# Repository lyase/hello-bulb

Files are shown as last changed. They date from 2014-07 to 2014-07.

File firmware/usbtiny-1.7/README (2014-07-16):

USBtiny
=======

USBtiny is a software implementation of the USB low-speed protocol for
the Atmel ATtiny microcontrollers. Of course, it will also work on the
ATmega series. The software is written for an AVR clocked at 12 MHz.
At this frequency, each bit on the USB bus takes 8 clock cycles, and
with a lot of trickery, it is possible to decode and encode the USB
waveforms by software. The USB driver needs approximately 1250 to 1350
bytes of flash space (excluding the optional identification strings),
depending on the configuration and compiler version, and 46 bytes RAM
(excluding stack space). The C interface consists of 3 to 5 functions,
depending on the configuration.

Implementation
==============

USB uses two differential data signals, D+ and D-, which are normally
complementary. However, the end of a packet is signalled by pulling
both signals low. Data is not transmitted directly on the USB bus, it
is NRZI encoded first. This means that a "0" bit is encoded as a bit
change, and a "1" bit is encoded as no bit change. After 6 "1" bits,
"bit stuffing" takes place to force a change on the USB signal lines.

The software is interrupt driven: the start of a USB packet triggers
an interrupt. The interrupt handler synchronizes with the sync byte,
removes the NRZI encoding and bit stuffing, and stores the packed in
one of the two RAM buffers. Two buffers are used so that the next
packet can be received while the current one is being processed.
Depending on the packet type, a reply packed may be sent back
immediately in the interrupt handler.

The rest of the USB driver is written in C. A usb_poll() function
must to be called periodically to poll for incoming packets. Only a
single endpoint is supported at the moment. Standard control requests
are directly handled by the USB driver. Other SETUP requests are
forwarded to a user-supplied function usb_setup(). Support for large
replies and OUT control requests is optional, see usbtiny.h.

To use the USB driver in your own application, you need to configure
the macros in usbtiny.h, and provide a function usb_setup() to handle
SETUP control packets. Optionally, you need to provide the functions
usb_in() and usb_out(). Your code needs to call the initialization
function usb_init() at program startup, and usb_poll() at regular
intervals. The AVR device type and the upload command should be
configured at the top of the Makefile.

Other USB projects
==================

This software was inspired by two similar USB projects for the AVR,
especially the second one:

  http://www.cesko.host.sk/IgorPlugUSB/IgorPlug-USB%20(AVR)_eng.htm
  http://www.obdev.at/products/avrusb/index.html

The IgorPlugUSB code and earlier versions of the obdev code had the
restriction that the D+ signal must be connected to bit 0 of an I/O
port, in addition to an interrupt input. That means that for devices
like the ATtiny2313, three I/O pins are required to control the USB bus.
One of the reasons I wrote USBtiny was to have more freedom over which
I/O pins to use for the D+ and D- USB signals. The only restriction
is that both signals should be on the same I/O port. When you select a
pin for D+ that can also generate an interrupt, only two I/O pins are
required. Later versions of the obdev code have also removed this
restriction. The pin-change interrupt is deliberately not used, so
that it remains available for other uses. Another improvement is an
optional faster CRC calculation that uses a lookup table to calculate
4 bits at a time.

Apart from these advantages, I think that my code is more readable and
easier to configure, but that impression may be caused by a mild form
of the NIH syndrome that I'm suffering from. In any case, I learned a
lot about the USB protocol, and writing the interrupt handler was a
nice puzzle.

The USBtinyISP project is an AVR in-circuit programmer based on USBtiny,
and is available as a kit:

  http://www.ladyada.net/make/usbtinyisp/

Hardware
========

The AVR must be clocked with an external 12 MHz crystal. For an
ATtiny2313, this means that the low fuse byte must be reprogrammed,
for instance to 0xef. I also recommend to enable the BOD circuit,
when available. For the ATtiny2313, this means programming the high
fuse byte to 0xdb (BOD level is 2.7V).

The USB data signals are specified at 3.3V. The easiest way to
accomplish this is to use a 3.3V power supply for the AVR. However,
driving the USB signals with 5V seems to work as well in most cases,
which may be more convenient when you need to interface to 5V
peripherals. According to the USB specification, a device should not
be damaged by 5V signals. I've been running the AVR and USB bus at 5V,
and haven't encounter any problems so far, but I have some reports
of PCs and laptops that do not work with 5V signals. In that case,
you can reduce the voltage of the USB data signals by adding 3V6 zener
diodes from the data signals to ground.

USBtiny SPI converter
=====================

My first USBtiny application is a USB to SPI (Serial Programming
Interface) converter. The SPI signals are connected to a female DB-25
connecter, so that the converter can be plugged onto my AVR parallel
port programmer. Because the most important parallel port signals are
connected to the DB-25 connecter, the same hardware (with different
firmware) could be used to control other parallel port devices. That
is also the reason why I connected the ACK signal to the INT1 pin.
The software, the schematic and a Python test script can be found
in the "spi" subdirectory.

My AVR parallel port programmer follows the "bsd" design from Brian
Dean (http://www.bsdhome.com/avrdude/). For safety, I've used series
resistors in the output signals. The Atmel device is powered by the
data lines D1-D3, via 220 Ohm resistors. D0 is used to control a LED.
Here is an ASCII-art version of the schematic:

DB25 male                          ATtiny2313
---------                          ----------
18 GND ----------------------+---- 10 GND
 2 D0  ---- 330 ---- LED ----+
 3 D1  ---- 220 ---+
 4 D2  ---- 220 ---+-------------- 20 VCC
 5 D3  ---- 220 ---+
 7 D5  ---- 1K -------------------  1 /RESET
 8 D6  ---- 680 ------------------ 19 SCK
 9 D7  ---- 1K ------------------- 17 MOSI
10 ACK --------------------------- 18 MISO

The USBtiny circuit may be powered via the diode at pin 14 of the
DB-25 connector to enable reprograming the ATtiny2313 in-system.
This requires an adaptor cable between another SPI programmer and
a DB-25 male connector with the following connections:

  SPI  DB25
  ---  ----
  GND    25
  VCC    14
  RESET  13
  SCK     9
  MISO    8
  MOSI    7

Bit-banging the SPI signals via USB turned out to be very slow. To get
reasonable programming speeds, I've moved the SPI algorithm into the
AVR. This means that you can send a 32-bit SPI command in a single USB
packet. In addition, you can read or write up to 255 bytes from/to
flash or EEPROM in a single control transfer.

The subdirectory "patches" contains a patch for avrdude-5.4 that adds
support for controlling this SPI converter. The programmer name is
"usbtiny". You can use the -B option or the "sck" command to specify
the minimum SCK period in microseconds (range: 1..250, default: 10).
Native support for USBtiny was added in avrdude version 5.5.

USBtiny LIRC compatible IR receiver and LCD controller
======================================================

A second USBtiny application is a receiver for infrared remote
controls that can be used with the LIRC package (http://www.lirc.org/).
The firmware stores the mark/space timings from a TSOP1738 IR decoder
in a buffer that is polled by a LIRC device driver. As a visual
feedback, a LED is flashed when a signal is being received. As an
additional (optional) feature, a 2x16 LCD display is attached to PORTB.
You can control the display via the USB bus. The software, the schematic
and a Python test script can be found in the "ir" subdirectory.
A pull-down resistor at PB3 prevents a hang in the LCD initialization
code when no LCD is attached to PORTB. You can disable the LCD code by
setting the LCD_PRESENT macro in main.c to 0.

I adopted the "IgorPlug-USB" protocol, so that the existing LIRC
device driver "igorplugusb" could be used without modifications.
Nevertheless, patches for lirc-0.8.0 and lirc-0.8.2 are included
in the "patches" subdirectory, with the following modifications:
1) An increase of the sample rate from 10 to 100 times per second.
   This is not required, but improves the responsiveness and repeat
   behavior for some remote controls.
2) A fix from Reinhard Max to get correct gap timings.
3) A compilation fix for the latest 2.6 Linux kernels (lirc-0.8.0).

USB AVR programmer and SPI interface
====================================

The subdirectory "usbtinyisp" contains a modified version of the "spi"
application, that was adapted for use in the USBtinyISP AVR programmer
(http://www.ladyada.net/make/usbtinyisp/). The code works for both v1.0
and v2.0 devices.

Template USBtiny application
============================

The directory "template" contains a minimal template application that
can be used as a starting point for new USBtiny applications.

Tools
=====

The software was developed on a Linux system. In addition to standard
tools like GNU make, you need the AVR versions of gcc, binutils and
glibc to build the code: On a Debian/Ubuntu system, you can apt-get
the following packages:

  gcc-avr
  binutils-avr
  avr-libc

To upload the code to an AVR, I use avrdude with a parallel port
programmer.

I initially used gcc-3.4.3 with the -Os option, which generates
reasonable compact code. Unfortunately, newer versions like gcc-4.1.0
generated about 10% more code, and as a result, the application code
did not fit in 2K anymore. To make it fit, I had to remove the optional
vendor and device strings, by undefining the USBTINY_VENDOR_NAME and
USBTINY_DEVICE_NAME macros. Fortunately, code generation has improved
in later versions such as gcc-4.3.4.

The schematics were created with gschem, from the geda-gschem package.
The conversion to Postscript is done with a script that invokes gschem
non-interactively.

The "util" and application code subdirectories each contain their own
Makefile. In addition, there is a global Makefile that recursively
invokes all other Makefiles.

Host software
=============

The subdirectory "utils" contains a Python module "usbtiny.py" that
defines a class USBtiny that can be used to communicate with the
USBtiny firmware. This class is used by the test scripts.

The usbtiny.py module uses a Python wrapper around libusb that is
generated by "swig". Type "make" to build the wrapper. You need to
have swig, libusb, libusb-dev and python-dev installed on your system.

Libusb needs appropriate permissions to open a USB device. This means
that you either have to run the scripts as "root", or you should
configure the hotplug or udev system to relax the permissions of the
device file created under /proc/bus/usb/ when the device is plugged
in. For instance, you can create a file 99-usbtiny.rules with the
following content in /etc/udev/rules.d/:

  SUBSYSTEM=="usb",ATTR{idVendor}=="1781",ATTR{idProduct}=="0c9f",GROUP="plugdev"

License
=======

The USBtiny software is licensed under the terms of the GNU General
Public License as published by the Free Software Foundation, either
version 2 of the license, or (at your option) any later version. A
copy of the GPL version 2 license can be found in the file COPYING.

Author & website
================

Dick Streefland <dick@streefland.net>

http://www.google.com/search?btnI&q=webtag_net_streefland_avr_usbtiny

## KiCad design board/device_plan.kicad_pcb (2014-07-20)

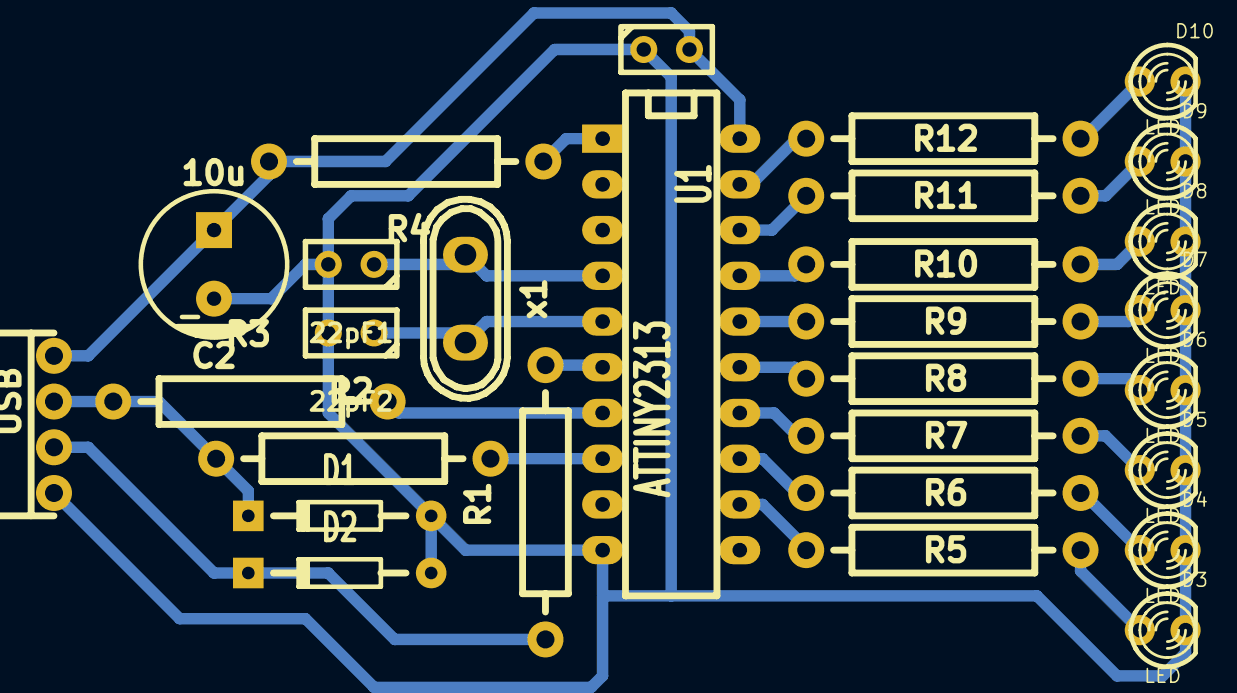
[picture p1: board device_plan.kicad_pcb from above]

Board: 2 copper layers, 29 parts (0 on the bottom side), 26 nets.

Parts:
22pF1, 22pF2: C; Capacitor3MMDiscRM2.5
C1: 100n; Capacitor3MMDiscRM2.5
C2: 10u; Capacitor8x13RM3.8
D1, D2: 3.6V; Diode_DO-35_SOD27_Horizontal_RM10
D3, D4, D5, D6, D7, D8, D9, D10: LED; LED-3MM
J1: USB; KK04_MC
R1, R2: 68 ohms; Resistor_Horizontal_RM15mm
R3: 1500 ohms; Resistor_Horizontal_RM15mm
R4: 10 kohms; Resistor_Horizontal_RM15mm
R5, R6, R7, R8, R9, R10, R11, R12: 47 ohms; Resistor_Horizontal_RM15mm
U1: ATTINY2313; DIP-20__300_ELL
x1: 12M; Crystal_HC50-U_Vertical

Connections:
GND: 22pF1.2, 22pF2.2, C1.1, C2.2, D1.1, D2.1, D3.2, D4.2, D5.2, D6.2, D7.2, D8.2, D9.2, D10.2, J1.4, U1.10
unnamed: 22pF1.1, U1.4, x1.1
unnamed: 22pF2.1, U1.5, x1.2
unnamed: D1.2, J1.2, R2.1, R3.1
unnamed: D2.2, J1.3, R1.1
unnamed: D3.1, R5.1
unnamed: D4.1, R6.1
unnamed: D5.1, R7.1
unnamed: D6.1, R8.1
unnamed: D7.1, R9.1
unnamed: D8.1, R10.1
unnamed: D9.1, R11.1
unnamed: D10.1, R12.1
unnamed: R1.2, U1.6
unnamed: R2.2, U1.8
unnamed: R3.2, U1.7
unnamed: R4.1, U1.1
unnamed: R5.2, U1.12
unnamed: R6.2, U1.13
unnamed: R7.2, U1.14
unnamed: R8.2, U1.15
unnamed: R9.2, U1.16
unnamed: R10.2, U1.17
unnamed: R11.2, U1.18
unnamed: R12.2, U1.19
VCC: C1.2, C2.1, J1.1, R4.2, U1.20

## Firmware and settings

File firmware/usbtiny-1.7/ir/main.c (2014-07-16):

// ======================================================================
// IR receiver and LCD controller with USB interface.
//
// Read IR mark/space patterns from a TSOP1738 on the ICP input pin.
// Mark and space periods are measured in units of 12Mhz/1024, which is
// 85.33 us. Up to 36 periods are stored in a buffer, where they can
// be read via a USB request. The buffer layout and USB requests are
// compatible with the "IgorPlug-USB" device, which is supported by LIRC
// through the "igorplugusb" driver. This implementation should also
// work with that driver. If IgorPlug-USB compatibility is not required,
// the resolution could be improved by reducing SCALING to 9, and you
// could also get rid of the additional endpoint (USBTINY_ENDPOINT).
//
// There are some IR protocols with very long packets length, such as
// the "NEC" protocol (http://www.sbprojects.com/knowledge/ir/nec.htm).
// This protocol uses 67 mark/space periods, which is too much for the
// limited amount of RAM in the ATtiny2313. Simply truncating the
// packet to the amount of available buffer space is not an option,
// because the significant bits are at the end of the packet. Instead,
// a buffer of 36 bytes (IR_MAX) is used, of which the last 16 bytes
// (IR_WRAP) are used as a circular buffer. Because both the address
// (16 periods) and the command code (16 periods) are sent twice (normal
// and inverted), the wrapping will result in a buffer with both the
// device address and the inverted command code. Other IR protocols are
// typically shorter than 36 periods.
//
// 16-bit Timer1 is initialized in normal mode with a clock of 12MHz/8.
// Both the positive and negative edges of the IR input signal on the
// ICP input pin trigger an input capture interrupt, because the edge
// selection is toggled on every interrupt. Output compare register A
// is used for a timeout to detect the end of an IR transmission.
// The timeout value is updated on every edge. When at least 4 edges
// were detected when a timeout occurs, the packet count ir.count is
// incremented and the ir.length byte is set to the packed length. This
// byte is checked when a read request is received via USB to see if a
// packet is available
//
// The two interrupt handlers in this file run for more than 28 cycles,
// so they need to reenable interrupts to allow USB interrupts to be
// handled in time. To avoid nested IR interrupts, the input capture and
// output compare interrupts are disabled before the global interrupt
// flag is set. In the input capture interrupt handler, the interrupts
// are disabled for a maximum of 27, 27 and 27 cycles, and in the output
// compare interrupt handler for 21, 23 and 22 cycles. Unfortunately,
// it was not possible to meet the 28 cycle maximum for the input
// capture interrupt handler without using some inline assembly.
// Because the limits are so tight, the code is fragile, and may break
// for a new gcc version.
//
// The IR receiver is disabled during an IR buffer read, so that a
// packet that is being tranmitted to the host, is not overwritten by
// the next packet. When a transfer is in progress, 'inpos' has a value
// other than 0xff. When the buffer is read completely, the IR receiver
// is reenabled again, but when the next IR packet has already started,
// this packed is discarded by setting 'edges' to 0xff.
//
// There are two USB request codes to control the LCD, one to write
// instructions, and one to write data to the display. OUT transfers
// are used to transfer up to 255 bytes for a single request.
//
// Stack space calculations for gcc-4.1.0 and gcc-4.3.4:
//
//   0  main (stack reset)
//   0      lcd_init (inlined)
//   0      ir_init (inlined)
//   2      usb_init
//   5      usb_poll
//   0          usb_receive (inlined)
//   2              usb_setup
//   5              usb_out
//   3                  lcd_write
//   0                      lcd_read4 (inlined)
//   2                      lcd_write4
//   0          usb_transmit (inlined)
//   4              usb_int
//   2              crc
//
// Maximum stack space is 5+5+3+2=15.
// Total stack usage:
// - USB interrupt:			11 bytes
// - IR input capture interrupt:	12 bytes
// - IR output compare interrupt: 	 7 bytes
// - main():				15 bytes
// The two IR interrupt handler cannot be active simultaneously, so the
// maximum stack space is 15+12+11=38 bytes.
//
// NOTE: The above cycle and stack size figures were obtained by
//       inspecting the code generated by gcc-4.1.0 and gcc-4.3.4.
//       Other compiler versions may generate different code, leading
//       to different figures.
//
// Copyright 2006-2010 Dick Streefland
//
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
#include <avr/io.h>
#include <avr/interrupt.h>
#include "def.h"
#include "usb.h"

// ----------------------------------------------------------------------
// IR receiver definitions
// ----------------------------------------------------------------------

#define	TIMEOUT		10500	// IR transmission timeout in us
#define	IR_MAX		36	// maximum number of IR data bytes
#define	IR_WRAP		16	// wrap area at end (for 67 byte NEC protocol)
#define	SCALING		10	// 9: 42.67 us period, 10: 85.33 us period
#define	LED		(D,5)	// I/O port for LED

enum
{
	// Generic requests
	USBTINY_ECHO,		// echo test
	// IgorPlug-USB requests
	IGORPLUG_CLEAR,		// clear IR data
	IGORPLUG_READ,		// read IR data (wValue: offset)
	// LCD requests
	LCD_INSTR = 20,		// write instructions to LCD (via OUT)
	LCD_DATA,		// write data to LCD (via OUT)
};

static	byte_t	inpos;		// read position for usb_in(), or 0xff
static	byte_t	edges;		// incremented for each edge
static	struct			// IgorPlug-USB compatible data layout
{
	byte_t	length;		// length of data[]
	byte_t	count;		// incremented for each IR packet
	byte_t	offset;		// not used
	byte_t	data[IR_MAX];	// mark/space periods
}		ir;

// ----------------------------------------------------------------------
// LCD definitions
// ----------------------------------------------------------------------

#define	LCD_PRESENT	1	// set to 0 to remove LCD support

#define	DDR		DDRB
#define	PORT		PORTB
#define	PIN		PINB

#define	D4		0
#define	RS		4
#define	RW		5
#define	E		6

#define	MASK_D4		(0xf << D4)
#define	MASK_RS		(1 << RS)
#define	MASK_RW		(1 << RW)
#define	MASK_E		(1 << E)

#ifndef	ICIE1
#define	ICIE1		TICIE1
#endif

// ----------------------------------------------------------------------
// Handler for timer1 input capture interrupt: edge on IR input
// ----------------------------------------------------------------------
ISR(TIMER1_CAPT_vect)
{
	static	uint_t	prev;
	uint_t		stamp;
	byte_t		delta;
	byte_t		e;

	TIMSK = 0;				// disable both IR interrupts
	sei();					// allow USB interrupt
	TCCR1B ^= _BV(ICES1);			// toggle edge detector
	stamp = ICR1;				// get time stamp
	asm volatile(
		"push	%A0\n"			// save stamp
		"push	%B0\n"
		:
		: "w"(stamp), "w"(prev)		// "w"(prev) reduces register usage
	);
	stamp -= prev;				// calculate delta in-place
	stamp += 1 << (SCALING - 3 - 1);	// round
	stamp >>= (SCALING - 3);		// scale
	asm volatile(
		"mov	%0,%A1\n"		// delta = stamp & 0xff
		"pop	%B1\n"
		"pop	%A1\n"			// restore stamp
		: "=r"(delta)
		: "w"(stamp)
	);
	prev  = stamp;
	OCR1A = stamp + 12L * TIMEOUT / 8;	// update timeout value
	cli();					// enter critical region
	e = edges;
	if	( e != 0xff )			// packet should not be ignored?
	{
		if	( e > IR_MAX )		// packet too long for buffer?
		{
			e -= IR_WRAP;		// wrap, don't truncate
		}
		if	( inpos == 0xff )	// update ir only when USB idle
		{
			ir.length = 0;		// discard previous packet
			if	( e > 0 )
			{
				ir.data[e - 1] = delta;
			}
		}
		edges = e + 1;
	}
	sei();					// allow USB interrupt
	SET(LED);				// switch LED on
	e = _BV(OCIE1A) | _BV(ICIE1);
	asm volatile("" :: "r"(e));		// force evaluation of "e"
	cli();
	TIMSK = e;				// reenable IR interrupts
}

// ----------------------------------------------------------------------
// Handler for timer1 output compare A interrupt: IR transmission timeout
// ----------------------------------------------------------------------
ISR(TIMER1_COMPA_vect)
{
	TIMSK = 0;				// disable both IR interrupts
	sei();					// allow USB interrupt
	CLR(LED);				// switch LED off
	cli();					// enter critical region
	if	(  edges >= 4			// at least two pulses (NEC)
		&& edges != 0xff		// packet should not be ignored
		&& inpos == 0xff		// update ir only when USB idle
		)
	{
		ir.count++;
		ir.length = edges - 1;		// new packet is complete
	}
	edges = 0;
	sei();					// allow USB interrupt
	TCCR1B &= ~_BV(ICES1);			// reset to negative edge
	cli();
	TIMSK = _BV(OCIE1A) | _BV(ICIE1);	// reenable IR interrupts
}

// ----------------------------------------------------------------------
// Initialize the IR receiver.
// ----------------------------------------------------------------------
static	void	ir_init ( void )
{
	OUTPUT(LED);
	TCCR1B = _BV(ICNC1)	// noise canceler, trigger on negative edge
	       | _BV(CS11);	// clock source clk/8
	TIMSK  = _BV(OCIE1A)	// output compare 1A match interrupt enable
	       | _BV(ICIE1);	// input capture 1 interrupt enable
}

#if	LCD_PRESENT
// ----------------------------------------------------------------------
// Delay <count> times 100 microseconds.
// ----------------------------------------------------------------------
__attribute__((noinline))
static	void	lcd_delay100u ( byte_t count )
{
	asm volatile(
		"0:	ldi	r25, 240\n"
		"1:	rjmp	2f\n"
		"2:	dec	r25\n"
		"	brne	1b\n"	// 240 * 5 cycles = 100us
		"	dec	r24\n"
		"	brne	0b\n"
	);
}

// ----------------------------------------------------------------------
// Write 4 bits to the LCD.
// ----------------------------------------------------------------------
__attribute__((noinline))
static	void	lcd_write4 ( byte_t data )
{
	PORT = (PORT & ~ MASK_D4) | (data << D4);
	PORT |= MASK_E;			// E high period: > 230ns
	DDR  = MASK_RS | MASK_RW | MASK_E | MASK_D4; // Dx setup time: > 80ns
	PORT &= ~ MASK_E;		// hold time: > 10ns
	DDR  = MASK_RS | MASK_RW | MASK_E;
}

// ----------------------------------------------------------------------
// Read 4 bits from the LCD.
// ----------------------------------------------------------------------
__attribute__((always_inline))
static	inline	byte_t	lcd_read4 ( void )
{
	byte_t	save;
	byte_t	data;

	save = PORT;
	PORT = MASK_RW;			// address setup time: > 40ns
	PORT |= MASK_E;			// E high period: > 230ns
	asm volatile("rjmp 0f\n0:");
	data = (PIN & MASK_D4) >> D4;	// data access time: > 160ns
	PORT = save;
	return data;
}

// ----------------------------------------------------------------------
// Write a byte to the LCD.
// ----------------------------------------------------------------------
static	void	lcd_write ( byte_t b )
{
	byte_t	h;

	do
	{
		h = lcd_read4();
		(void) lcd_read4();
	} while	( h & 0x08 );
	lcd_write4( b >> 4 );
	lcd_write4( b & 15 );
}

// ----------------------------------------------------------------------
// Initialize the LCD.
// ----------------------------------------------------------------------
static	void	lcd_init ( void )
{
	DDR = MASK_RS | MASK_RW | MASK_E;
	PORT = 0;
	//lcd_delay100u( 150 );	-- skipped because of RESET delay
	lcd_write4( 3 );
	lcd_delay100u( 41 );
	lcd_write4( 3 );
	lcd_delay100u( 1 );
	lcd_write( 0x32 );	// switch to 4-bit mode
	lcd_write( 0x28 );	// function set: 4-bit mode, two lines
	lcd_write( 0x01 );	// clear display
	lcd_write( 0x06 );	// entry mode: increment, no shift
	lcd_write( 0x0c );	// display control: on, no cursor
}
#endif	/* LCD_PRESENT */

// ----------------------------------------------------------------------
// Handle a non-standard SETUP packet.
// ----------------------------------------------------------------------
extern	byte_t	usb_setup ( byte_t data[8] )
{
	byte_t	req;
	byte_t	r;

	r = 0;

	// Generic requests
	req = data[1];
	if	( req == USBTINY_ECHO )
	{
		r = 8;
	}

	// IgorPlug-USB requests
	if	( req == IGORPLUG_CLEAR )
	{
		ir.length = 0;
		inpos = 0xff;
	}
	if	( req == IGORPLUG_READ )
	{
		cli();
		if	( ir.length > 0 )
		{
			inpos = data[2];
			r = 0xff;	// call usb_in() to get the data
		}
		else
		{
			data[0] = 0;
			r = 1;
		}
		sei();
	}

	// LCD requests
	if	( req == LCD_INSTR )
	{
		PORT &= ~ MASK_RS;	// data will be received by usb_out()
	}
	if	( req == LCD_DATA )
	{
		PORT |= MASK_RS;	// data will be received by usb_out()
	}

	return r;
}

// ----------------------------------------------------------------------
// Handle an IN packet.
// ----------------------------------------------------------------------
extern	byte_t	usb_in ( byte_t* data, byte_t len )
{
	byte_t	n;
	byte_t	max;

	max = ir.length + 3;
	n = 0;
	while	( n < len )
	{
		if	( inpos >= max )	// end of packet?
		{
			cli();
			if	( edges )	// next packet already started?
			{
				edges = 0xff;	// ignore remainder of packet
			}
			inpos = 0xff;		// reenable receiver
			sei();
			break;
		}
		data[n++] = (& ir.length)[inpos++];
	}
	return n;
}

// ----------------------------------------------------------------------
// Handle an OUT packet.
// ----------------------------------------------------------------------
extern	void	usb_out ( byte_t* data, byte_t len )
{
#if	LCD_PRESENT
	while	( len )
	{
		lcd_write( *data++ );
		len--;
	}
#endif	/* LCD_PRESENT */
}

// ----------------------------------------------------------------------
// Main
// ----------------------------------------------------------------------
extern	int	main ( void )
{
	SPL = (RAMEND & 0xff);			// drop return address of main
	inpos = 0xff;
#if	LCD_PRESENT
	lcd_init();
#endif	/* LCD_PRESENT */
	ir_init();
	usb_init();
	for	( ;; )
	{
		usb_poll();
	}
}

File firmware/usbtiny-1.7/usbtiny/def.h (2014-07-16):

// ======================================================================
// Common definitions for the USB driver
//
// Copyright 2006-2010 Dick Streefland
//
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
#ifdef __ASSEMBLER__
#define	__SFR_OFFSET		0
#endif
#include <avr/io.h>
#include "usbtiny.h"

// Preprocessor magic
#define	CAT2(a,b)		CAT2EXP(a, b)
#define	CAT2EXP(a,b)		a ## b
#define	CAT3(a,b,c)		CAT3EXP(a, b, c)
#define	CAT3EXP(a,b,c)		a ## b ## c

// I/O Ports for USB
#define	USB_IN			CAT2(PIN, USBTINY_PORT)
#define	USB_OUT			CAT2(PORT, USBTINY_PORT)
#define	USB_DDR			CAT2(DDR, USBTINY_PORT)

// I/O bit masks for USB
#define	USB_MASK_DMINUS		(1 << (USBTINY_DMINUS))
#define	USB_MASK_DPLUS		(1 << (USBTINY_DPLUS))
#define	USB_MASK		(USB_MASK_DMINUS | USB_MASK_DPLUS)

// Interrupt configuration
#if	defined	EICRA
#  define USB_INT_CONFIG	EICRA
#else
#  define USB_INT_CONFIG	MCUCR
#endif
#define	USB_INT_CONFIG_SET	((1 << CAT3(ISC,USBTINY_INT,1)) | (1 << CAT3(ISC,USBTINY_INT,0)))
#define USB_INT_VECTOR		CAT3(INT, USBTINY_INT, _vect)

// Interrupt enable
#if	defined	GIMSK
#  define USB_INT_ENABLE	GIMSK
#elif	defined	EIMSK
#  define USB_INT_ENABLE	EIMSK
#else
#  define USB_INT_ENABLE	GICR
#endif
#define	USB_INT_ENABLE_BIT	CAT2(INT,USBTINY_INT)

// Interrupt pending bit
#if	defined	EIFR
#  define USB_INT_PENDING	EIFR
#else
#  define USB_INT_PENDING	GIFR
#endif
#define	USB_INT_PENDING_BIT	CAT2(INTF,USBTINY_INT)
#if	defined INF0 && ! defined INTF0
#  define	INTF0		INF0	// fix for incorrect definition in iotn13.h
#endif

// USB PID values
#define	USB_PID_SETUP		0x2d
#define	USB_PID_OUT		0xe1
#define	USB_PID_IN		0x69
#define	USB_PID_DATA0		0xc3
#define	USB_PID_DATA1		0x4b
#define	USB_PID_ACK		0xd2
#define	USB_PID_NAK		0x5a
#define	USB_PID_STALL		0x1e

// Various constants
#define	USB_BUFSIZE		11	// PID + data + CRC

// Bit manipulation macros
#define	BIT_CLR(reg,bit)	{ (reg) &= ~ _BV(bit); }
#define	BIT_SET(reg,bit)	{ (reg) |=   _BV(bit); }
#define	BIT_TST(reg,bit)	(((reg) & _BV(bit)) != 0)

// I/O port manipulation macros
#define	DDR_CLR(p,b)		BIT_CLR(DDR  ## p, b)
#define	DDR_SET(p,b)		BIT_SET(DDR  ## p, b)
#define	PORT_CLR(p,b)		BIT_CLR(PORT ## p, b)
#define	PORT_SET(p,b)		BIT_SET(PORT ## p, b)
#define	PORT_TST(p,b)		BIT_TST(PORT ## p, b)
#define	PIN_TST(p,b)		BIT_TST(PIN  ## p, b)
#define	PIN_SET(p,b)		BIT_SET(PIN  ## p, b)

// Macros that can be used with an argument of the form (port,bit)
#define	INPUT(bit)		DDR_CLR bit
#define	OUTPUT(bit)		DDR_SET bit
#define	CLR(bit)		PORT_CLR bit
#define	SET(bit)		PORT_SET bit
#define	ISSET(bit)		PORT_TST bit
#define	TST(bit)		PIN_TST bit
#define	TOGGLE(bit)		PIN_SET bit

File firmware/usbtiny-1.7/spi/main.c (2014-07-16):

// ======================================================================
// Control a parallel port AVR programmer (avrdude type "bsd") via USB.
//
// Copyright 2006-2010 Dick Streefland
//
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
#include <avr/io.h>
#include "usb.h"

enum
{
	// Generic requests
	USBTINY_ECHO,		// echo test
	USBTINY_READ,		// read byte (wIndex:address)
	USBTINY_WRITE,		// write byte (wIndex:address, wValue:value)
	USBTINY_CLR,		// clear bit (wIndex:address, wValue:bitno)
	USBTINY_SET,		// set bit (wIndex:address, wValue:bitno)
	// Programming requests
	USBTINY_POWERUP,	// apply power (wValue:SCK-period, wIndex:RESET)
	USBTINY_POWERDOWN,	// remove power from chip
	USBTINY_SPI,		// issue SPI command (wValue:c1c0, wIndex:c3c2)
	USBTINY_POLL_BYTES,	// set poll bytes for write (wValue:p1p2)
	USBTINY_FLASH_READ,	// read flash (wIndex:address)
	USBTINY_FLASH_WRITE,	// write flash (wIndex:address, wValue:timeout)
	USBTINY_EEPROM_READ,	// read eeprom (wIndex:address)
	USBTINY_EEPROM_WRITE,	// write eeprom (wIndex:address, wValue:timeout)
};

// ----------------------------------------------------------------------
// Programmer output pins:
//	LED	PB0	(D0)
//	VCC	PB1	(D1)
//	VCC	PB2	(D2)
//	VCC	PB3	(D3)
//	RESET	PB5	(D5)
//	SCK	PB6	(D6)
//	MOSI	PB7	(D7)
// ----------------------------------------------------------------------
#define	PORT		PORTB
#define	DDR		DDRB
#define	POWER_MASK	0x0f
#define	RESET_MASK	(1 << 5)
#define	SCK_MASK	(1 << 6)
#define	MOSI_MASK	(1 << 7)

// ----------------------------------------------------------------------
// Programmer input pins:
//	MISO	PD3	(ACK)
// ----------------------------------------------------------------------
#define	PIN		PIND
#define	MISO_MASK	(1 << 3)

// ----------------------------------------------------------------------
// Local data
// ----------------------------------------------------------------------
static	byte_t		sck_period;	// SCK period in microseconds (1..250)
static	byte_t		poll1;		// first poll byte for write
static	byte_t		poll2;		// second poll byte for write
static	uint_t		address;	// read/write address
static	uint_t		timeout;	// write timeout in usec
static	byte_t		cmd0;		// current read/write command byte
static	byte_t		cmd[4];		// SPI command buffer
static	byte_t		res[4];		// SPI result buffer

// ----------------------------------------------------------------------
// Delay exactly <sck_period> times 0.5 microseconds (6 cycles).
// ----------------------------------------------------------------------
__attribute__((always_inline))
static	inline	void	delay ( void )
{
	asm volatile(
		"	mov	__tmp_reg__,%0	\n"
		"0:	rjmp	1f		\n"
		"1:	nop			\n"
		"	dec	__tmp_reg__	\n"
		"	brne	0b		\n"
		: : "r" (sck_period) );
}

// ----------------------------------------------------------------------
// Issue one SPI command.
// ----------------------------------------------------------------------
static	void	spi ( byte_t* cmd, byte_t* res )
{
	byte_t	i;
	byte_t	c;
	byte_t	r;
	byte_t	mask;

	for	( i = 0; i < 4; i++ )
	{
		c = *cmd++;
		r = 0;
		for	( mask = 0x80; mask; mask >>= 1 )
		{
			if	( c & mask )
			{
				PORT |= MOSI_MASK;
			}
			delay();
			PORT |= SCK_MASK;
			delay();
			r <<= 1;
			if	( PIN & MISO_MASK )
			{
				r++;
			}
			PORT &= ~ MOSI_MASK;
			PORT &= ~ SCK_MASK;
		}
		*res++ = r;
	}
}

// ----------------------------------------------------------------------
// Create and issue a read or write SPI command.
// ----------------------------------------------------------------------
static	void	spi_rw ( void )
{
	uint_t	a;

	a = address++;
	if	( cmd0 & 0x80 )
	{	// eeprom
		a <<= 1;
	}
	cmd[0] = cmd0;
	if	( a & 1 )
	{
		cmd[0] |= 0x08;
	}
	cmd[1] = a >> 9;
	cmd[2] = a >> 1;
	spi( cmd, res );
}

// ----------------------------------------------------------------------
// Handle a non-standard SETUP packet.
// ----------------------------------------------------------------------
extern	byte_t	usb_setup ( byte_t data[8] )
{
	byte_t	bit;
	byte_t	mask;
	byte_t*	addr;
	byte_t	req;

	// Generic requests
	req = data[1];
	if	( req == USBTINY_ECHO )
	{
		return 8;
	}
	addr = (byte_t*) (int) data[4];
	if	( req == USBTINY_READ )
	{
		data[0] = *addr;
		return 1;
	}
	if	( req == USBTINY_WRITE )
	{
		*addr = data[2];
		return 0;
	}
	bit = data[2] & 7;
	mask = 1 << bit;
	if	( req == USBTINY_CLR )
	{
		*addr &= ~ mask;
		return 0;
	}
	if	( req == USBTINY_SET )
	{
		*addr |= mask;
		return 0;
	}

	// Programming requests
	if	( req == USBTINY_POWERUP )
	{
		sck_period = data[2];
		mask = POWER_MASK;
		if	( data[4] )
		{
			mask |= RESET_MASK;
		}
		DDR  = 0xff;
		PORT = mask;
		return 0;
	}
	if	( req == USBTINY_POWERDOWN )
	{
		PORT |= RESET_MASK;
		PORT = 0x00;
		DDR  = 0x00;
		return 0;
	}
	if	( ! PORT )
	{
		return 0;
	}
	if	( req == USBTINY_SPI )
	{
		spi( data + 2, data + 0 );
		return 4;
	}
	if	( req == USBTINY_POLL_BYTES )
	{
		poll1 = data[2];
		poll2 = data[3];
		return 0;
	}
	address = * (uint_t*) & data[4];
	if	( req == USBTINY_FLASH_READ )
	{
		cmd0 = 0x20;
		return 0xff;	// usb_in() will be called to get the data
	}
	if	( req == USBTINY_EEPROM_READ )
	{
		cmd0 = 0xa0;
		return 0xff;	// usb_in() will be called to get the data
	}
	timeout = * (uint_t*) & data[2];
	if	( req == USBTINY_FLASH_WRITE )
	{
		cmd0 = 0x40;
		return 0;	// data will be received by usb_out()
	}
	if	( req == USBTINY_EEPROM_WRITE )
	{
		cmd0 = 0xc0;
		return 0;	// data will be received by usb_out()
	}
	return 0;
}

// ----------------------------------------------------------------------
// Handle an IN packet.
// ----------------------------------------------------------------------
extern	byte_t	usb_in ( byte_t* data, byte_t len )
{
	byte_t	i;

	for	( i = 0; i < len; i++ )
	{
		spi_rw();
		data[i] = res[3];
	}
	return len;
}

// ----------------------------------------------------------------------
// Handle an OUT packet.
// ----------------------------------------------------------------------
extern	void	usb_out ( byte_t* data, byte_t len )
{
	byte_t	i;
	uint_t	usec;
	byte_t	r;

	for	( i = 0; i < len; i++ )
	{
		cmd[3] = data[i];
		spi_rw();
		cmd[0] ^= 0x60;	// turn write into read
		for	( usec = 0; usec < timeout; usec += 32 * sck_period )
		{	// when timeout > 0, poll until byte is written
			spi( cmd, res );
			r = res[3];
			if	( r == cmd[3] && r != poll1 && r != poll2 )
			{
				break;
			}
		}
	}
}

// ----------------------------------------------------------------------
// Main
// ----------------------------------------------------------------------
extern	int	main ( void )
{
	usb_init();
	for	( ;; )
	{
		usb_poll();
	}
}

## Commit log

2014-07-08 introduce scientific wild guess for board design
    [device_plan.brd, device_plan.sch]
2014-07-08 fix missing zener diodes for usb specs
    [device_plan.brd, device_plan.sch]
2014-07-16 include footPrints
2014-07-16 initial firmware
    [ir.sch, spi.sch]
2014-07-16 get firmware to compile. updgraded to usbtiny-1.7 as few files of 1.4 may be broken empty !!
    [ir.sch, spi.sch]
2014-07-17 Reorganized schematic. Fixed input zener errors.
    [device_plan.sch]
2014-07-19 Modified schematic according to project
    [device_plan.sch]
2014-07-19 Assigns footprints, rough placement on board (new board file)
    [device_plan.brd, device_plan.kicad_pcb]
2014-07-19 add missing MakeFile for usb-device-firmware
2014-07-19 Laid traces on pcb. Added .gitignore.
    [device_plan.kicad_pcb]
2014-08-11 correct bug for 8 bit controler
    [main.c]
2014-08-15 add script to build latest kicad from source

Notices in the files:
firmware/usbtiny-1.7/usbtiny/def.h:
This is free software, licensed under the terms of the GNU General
